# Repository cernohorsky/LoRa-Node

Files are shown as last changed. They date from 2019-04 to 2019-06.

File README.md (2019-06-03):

# LoRa Node

Simple, cheap, very small size Lora node with PCB antenna on 868 MHz. Compatible with FT232RL FTDI USB To TTL Serial Converter. Design includes lot of free GPIO's, push button and LED.

It's necessary to <b>burn bootloader with ISP before RFM95W module is soldered</b>.

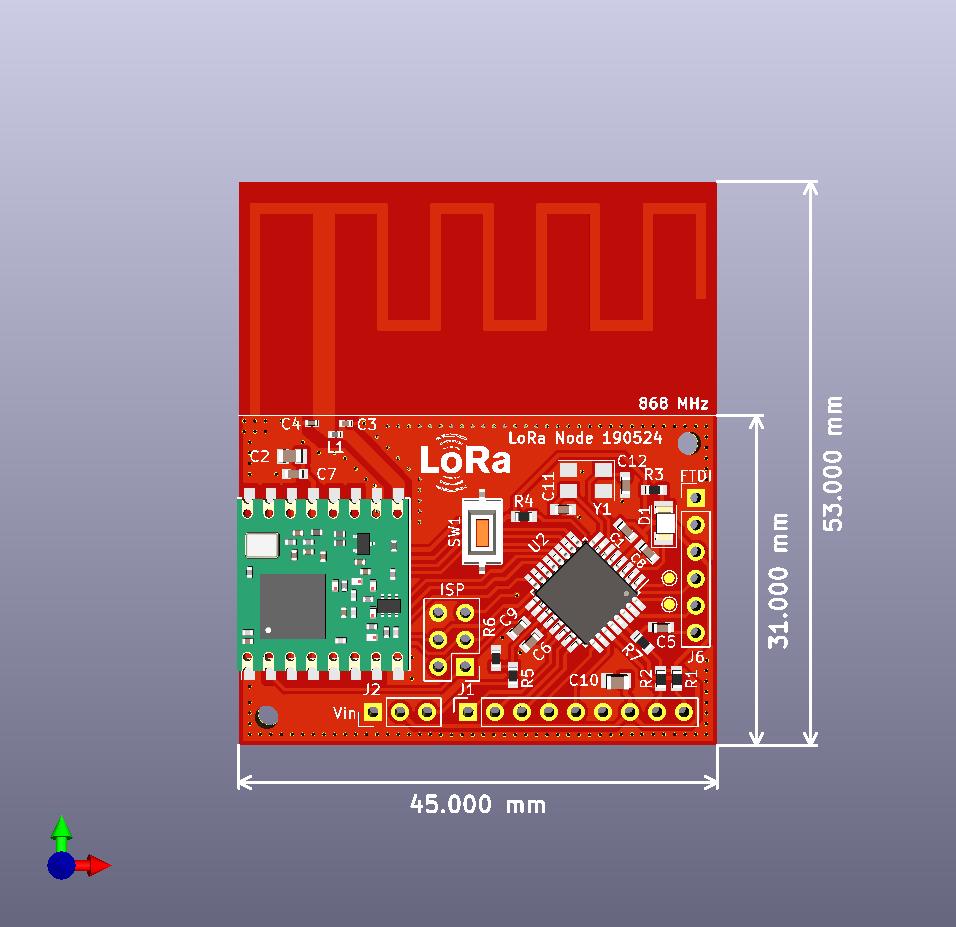
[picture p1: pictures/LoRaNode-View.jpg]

<b>Schematic</b>
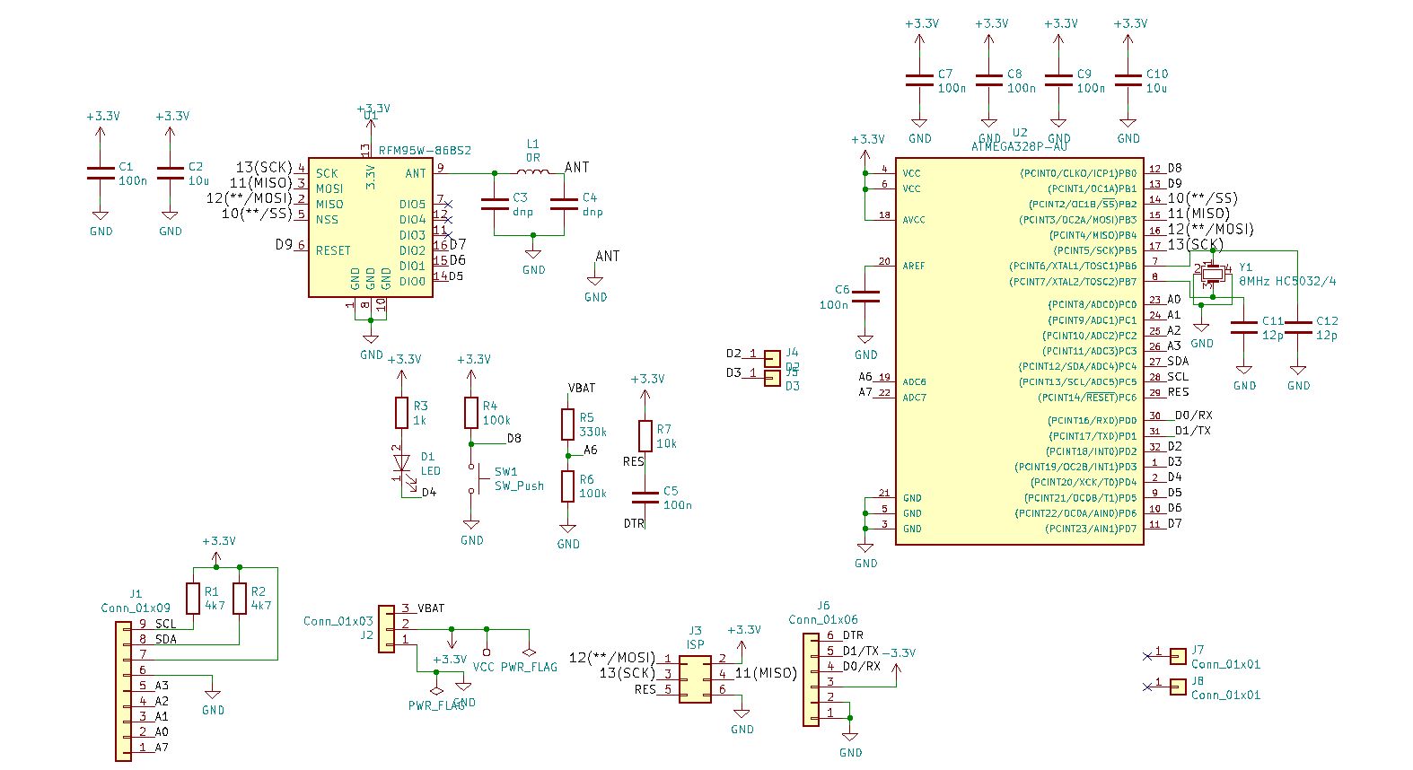
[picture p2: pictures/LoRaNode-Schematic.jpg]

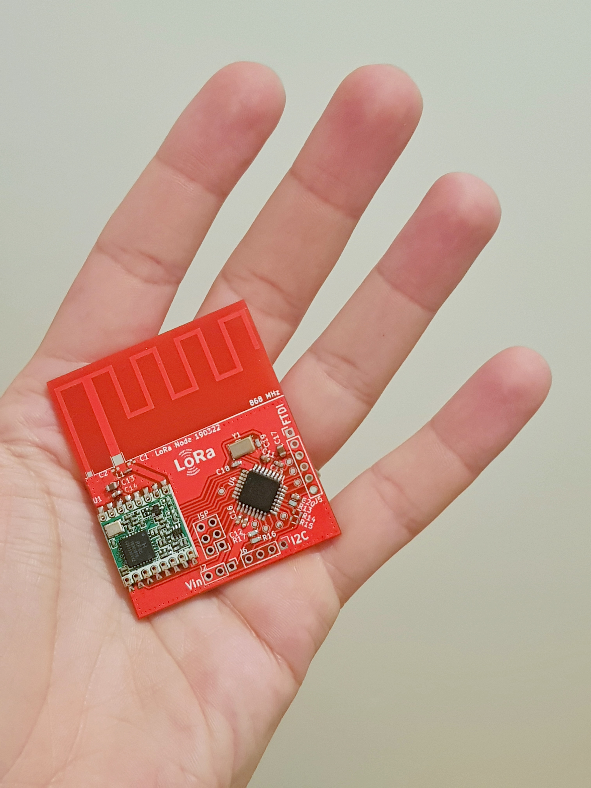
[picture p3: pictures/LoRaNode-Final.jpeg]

<b> S11 Measurement </b>
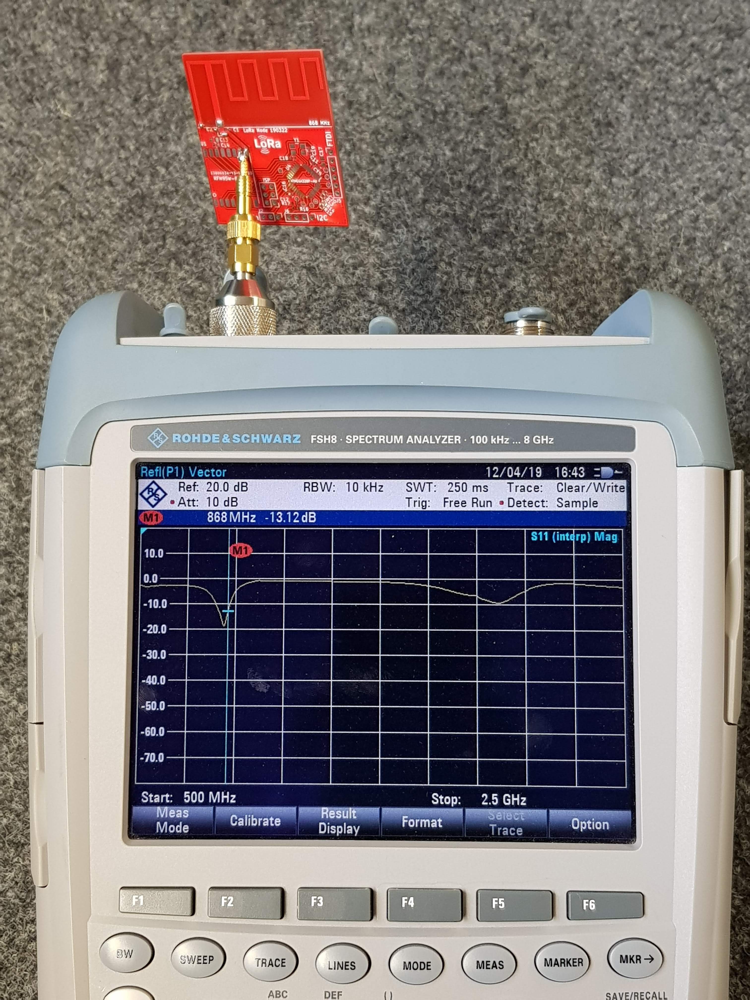
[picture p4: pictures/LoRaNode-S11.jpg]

<b> Sleep current measurement </b>
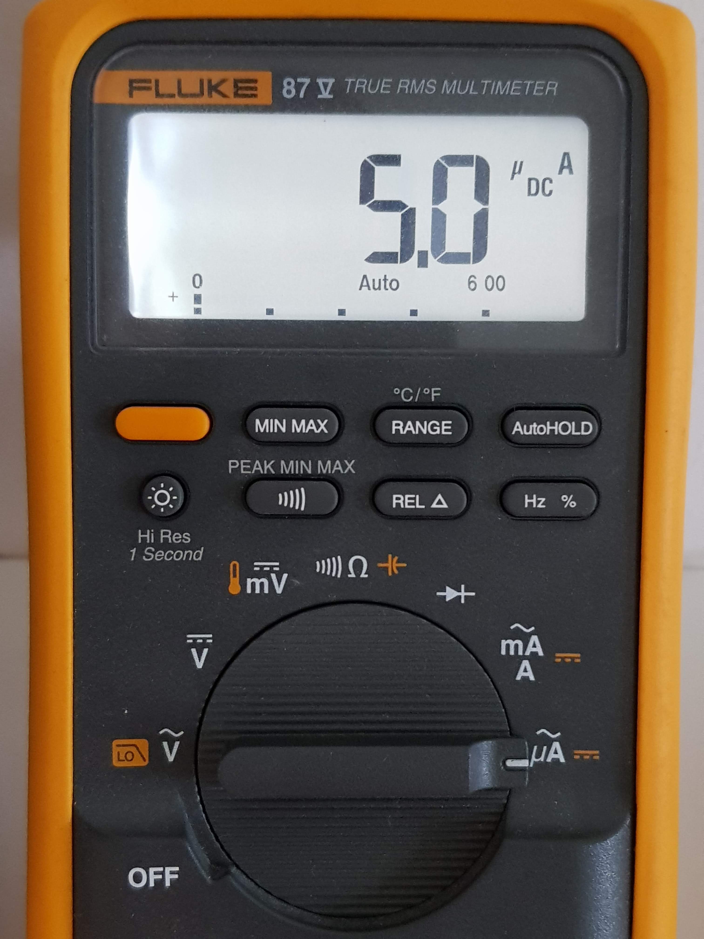
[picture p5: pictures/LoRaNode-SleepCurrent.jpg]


Based on: http://www.ti.com/lit/an/swra228c/swra228c.pdf

#RFM95W, #ATMEGA328P, #arduino, #lora, #pcb antenna, #inverted f antenna

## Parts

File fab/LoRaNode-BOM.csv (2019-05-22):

Id | Designator | Package | Quantity | Designation | Supplier and ref
17 | C1,C6,C7,C8,C9,C5 | C_0603_1608Metric | 6 | 100n
7 | C10,C2 | C_0805_2012Metric | 2 | 10u
18 | C11,C12 | C_0603_1608Metric | 2 | 12p
16 | C3,C4 | C_0402_1005Metric | 2 | dnp
15 | D1 | LED_1206_3216Metric | 1 | LED
13 | J1 | PinSocket_1x09_P2.54mm_Vertical | 1 | Conn_01x09
9 | J2 | PinHeader_1x03_P2.54mm_Vertical | 1 | Conn_01x03
2 | J3 | Pin_Header_Straight_2x03_Pitch2.54mm | 1 | ISP
3 | J6 | Pin_Header_Straight_1x06_Pitch2.54mm | 1 | Conn_01x06
19 | L1 | L_0402_1005Metric | 1 | 0R
21 | R1,R2 | R_0603_1608Metric | 2 | 4k7
14 | R3 | R_0603_1608Metric | 1 | 1k
5 | R5 | R_0603_1608Metric | 1 | 330k
6 | R6,R4 | R_0603_1608Metric | 2 | 100k
20 | R7 | R_0603_1608Metric | 1 | 10k
11 | SW1 | SMD-PushButton-6x3.6mm | 1 | SW_Push
1 | U1 | HOPERF_RFM95W_SMD | 1 | RFM95W-868S2
22 | U2 | TQFP-32_7x7mm_P0.8mm | 1 | ATMEGA328P-AU
4 | Y1 | Crystal_SMD_5032-4pin_5.0x3.2mm | 1 | 8MHz HC5032/4

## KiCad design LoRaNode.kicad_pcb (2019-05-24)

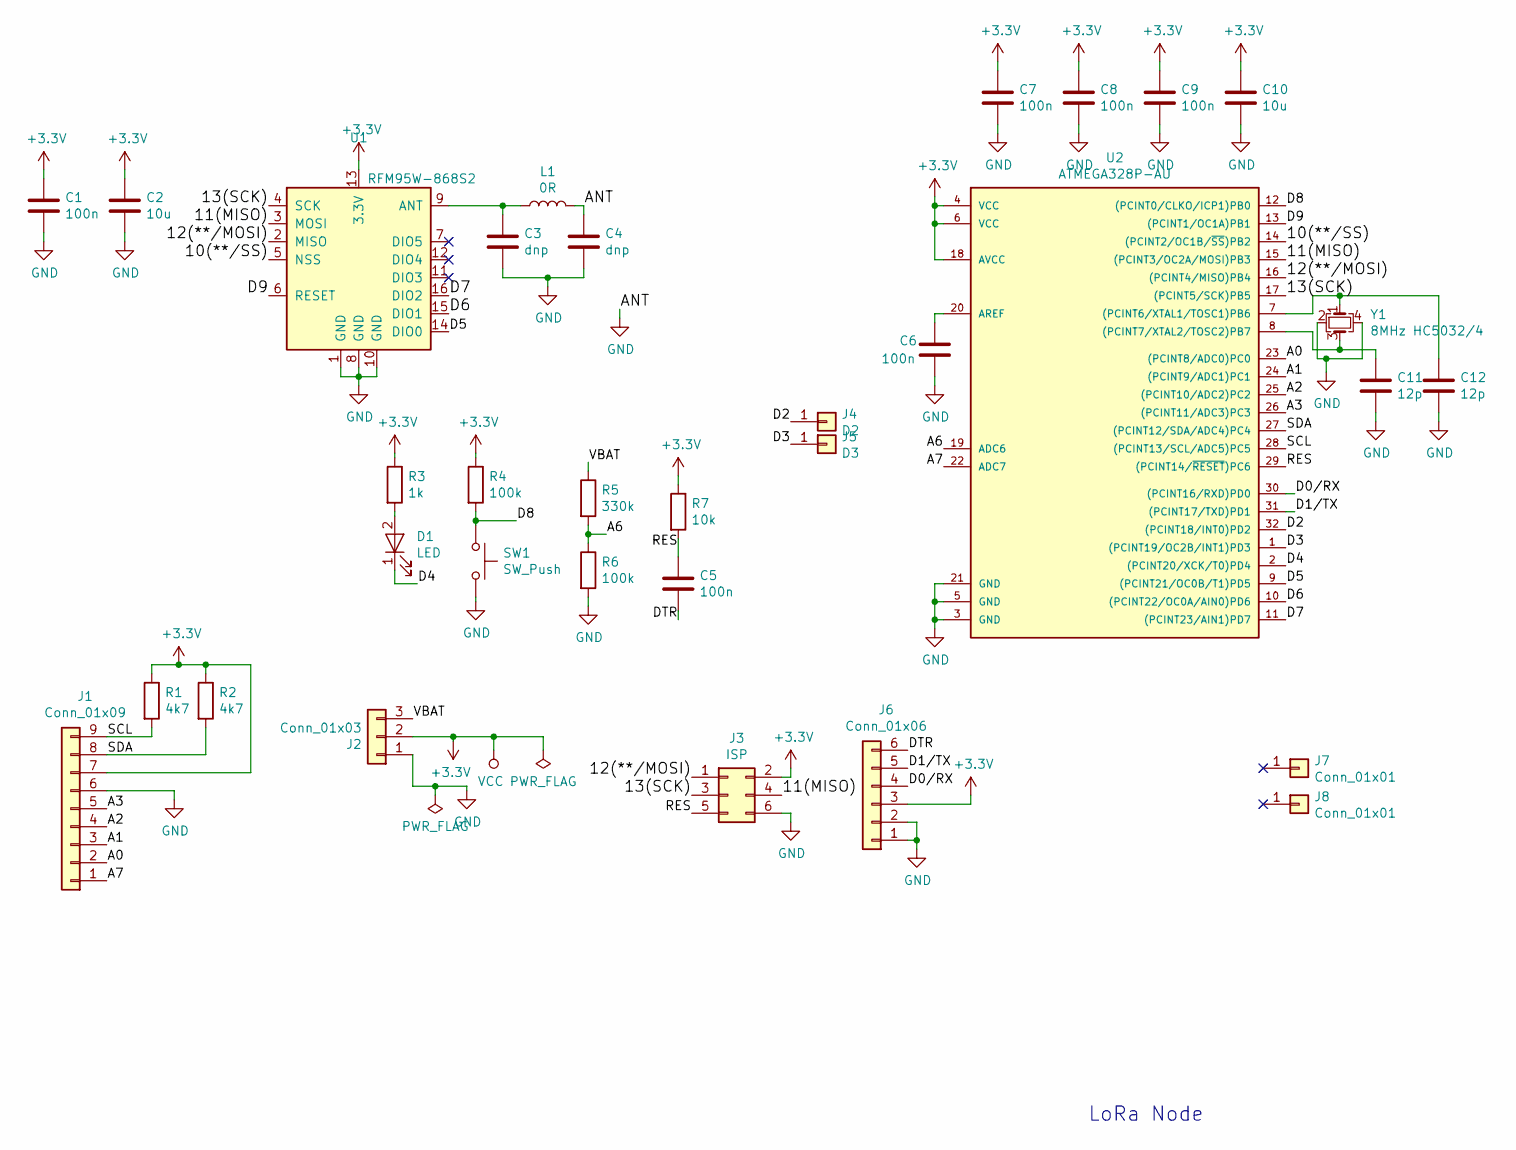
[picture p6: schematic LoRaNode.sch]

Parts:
C1, C5, C6, C7, C8, C9: 100n; C_0603_1608Metric
C2, C10: 10u; C_0805_2012Metric
C3, C4: dnp; C_0402_1005Metric
C11, C12: 12p; C_0603_1608Metric
D1: LED; LED_1206_3216Metric
J1: Conn_01x09; PinSocket_1x09_P2.54mm_Vertical
J2: Conn_01x03; PinHeader_1x03_P2.54mm_Vertical
J3: ISP; Pin_Header_Straight_2x03_Pitch2.54mm
J4: D2; TestPoint_Pad_D1.0mm
J5: D3; TestPoint_Pad_D1.0mm
J6: Conn_01x06; Pin_Header_Straight_1x06_Pitch2.54mm
J7, J8: Conn_01x01; MountingHole_2.2mm_M2
L1: 0R; L_0402_1005Metric
R1, R2: 4k7; R_0603_1608Metric
R3: 1k; R_0603_1608Metric
R4, R6: 100k; R_0603_1608Metric
R5: 330k; R_0603_1608Metric
R7: 10k; R_0603_1608Metric
SW1: SW_Push; SMD-PushButton-6x3.6mm
U1: RFM95W-868S2; HOPERF_RFM95W_SMD
U2: ATMEGA328P-AU; TQFP-32_7x7mm_P0.8mm
Y1: 8MHz HC5032/4; Crystal_SMD_5032-4pin_5.0x3.2mm

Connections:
+3V3: C1.1, C2.1, C7.1, C8.1, C9.1, C10.1, J1.7, J2.2, J3.2, J6.3, R1.1, R2.1, R3.1, R4.1, R7.1, U1.13 (3.3V), U2.4 (VCC), U2.6 (VCC), U2.18 (AVCC)
/10(**/SS): U1.5 (NSS), U2.14 ((PCINT2/OC1B/~SS~)PB2)
/11(MISO): J3.4, U1.3 (MOSI), U2.15 ((PCINT3/OC2A/MOSI)PB3)
/12(**/MOSI): J3.1, U1.2 (MISO), U2.16 ((PCINT4/MISO)PB4)
/13(SCK): J3.3, U1.4 (SCK), U2.17 ((PCINT5/SCK)PB5)
/A0: J1.2, U2.23 ((PCINT8/ADC0)PC0)
/A1: J1.3, U2.24 ((PCINT9/ADC1)PC1)
/A2: J1.4, U2.25 ((PCINT10/ADC2)PC2)
/A3: J1.5, U2.26 ((PCINT11/ADC3)PC3)
/A6: R5.2, R6.1, U2.19 (ADC6)
/A7: J1.1, U2.22 (ADC7)
/D0/RX: J6.4, U2.30 ((PCINT16/RXD)PD0)
/D1/TX: J6.5, U2.31 ((PCINT17/TXD)PD1)
/D2: J4.1, U2.32 ((PCINT18/INT0)PD2)
/D3: J5.1, U2.1 ((PCINT19/OC2B/INT1)PD3)
/D4: D1.1 (K), U2.2 ((PCINT20/XCK/T0)PD4)
/D5: U1.14 (DIO0), U2.9 ((PCINT21/OC0B/T1)PD5)
/D6: U1.15 (DIO1), U2.10 ((PCINT22/OC0A/AIN0)PD6)
/D7: U1.16 (DIO2), U2.11 ((PCINT23/AIN1)PD7)
/D8: R4.2, SW1.1, U2.12 ((PCINT0/CLKO/ICP1)PB0)
/D9: U1.6 (RESET), U2.13 ((PCINT1/OC1A)PB1)
/DTR: C5.2, J6.6
/RES: C5.1, J3.5, R7.2, U2.29 ((PCINT14/~RESET~)PC6)
/SCL: J1.9, R1.2, U2.28 ((PCINT13/SCL/ADC5)PC5)
/SDA: J1.8, R2.2, U2.27 ((PCINT12/SDA/ADC4)PC4)
/VBAT: J2.3, R5.1
GND: C1.2, C2.2, C3.2, C4.1, C4.2, C6.2, C7.2, C8.2, C9.2, C10.2, C11.2, C12.2, J1.6, J2.1, J3.6, J6.1, J6.2, L1.2, R6.2, SW1.2, U1.1 (GND), U1.8 (GND), U1.10 (GND), U2.3 (GND), U2.5 (GND), U2.21 (GND), Y1.2, Y1.4
unnamed: C3.1, L1.1, U1.9 (ANT)
unnamed: C6.1, U2.20 (AREF)
unnamed: C11.1, U2.8 ((PCINT7/XTAL2/TOSC2)PB7), Y1.3
unnamed: C12.1, U2.7 ((PCINT6/XTAL1/TOSC1)PB6), Y1.1
unnamed: D1.2 (A), R3.2

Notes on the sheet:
LoRa Node

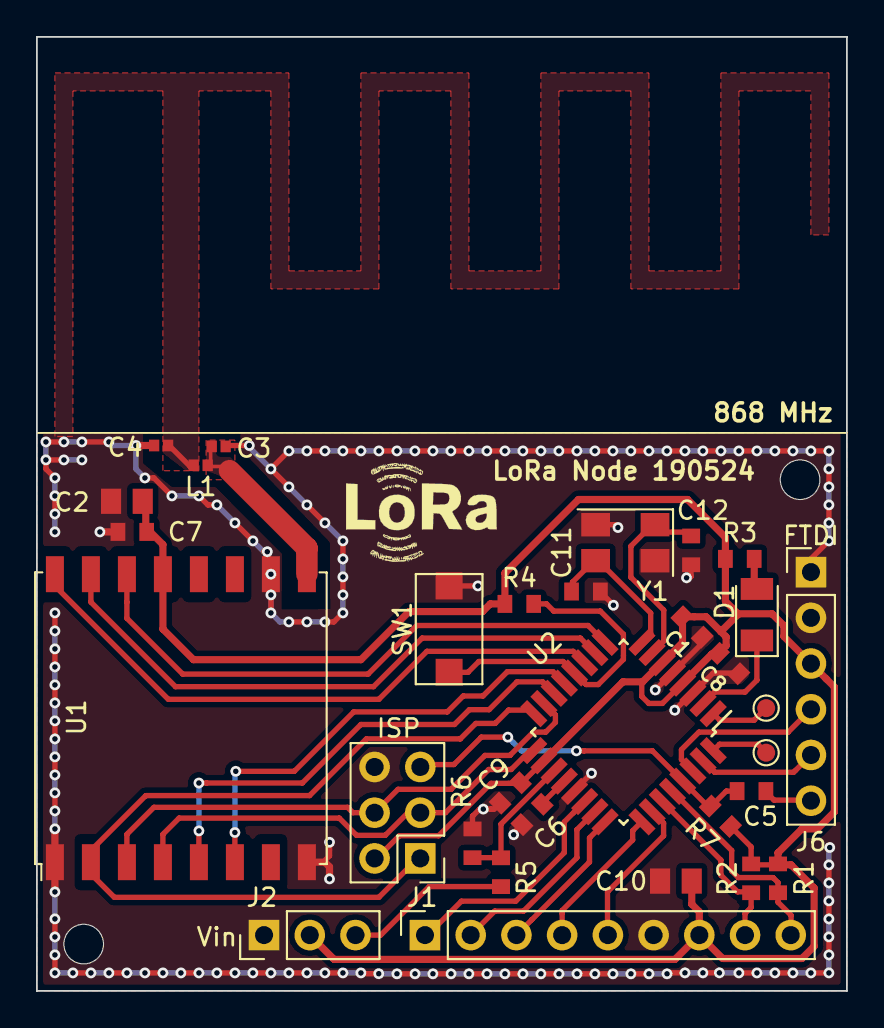
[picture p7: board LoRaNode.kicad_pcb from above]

Board: 2 copper layers, 45.0 x 53.0 mm, 33 parts (0 on the bottom side), 32 nets.

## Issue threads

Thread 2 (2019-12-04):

What board thickness is used?

Neumi, 2019-12-04:
If im not wrong board thickness has an influence on the impedance in the RF circuit and feed line. Can you tell what board you're using?
Thanks alot for the share!

krlc, 2020-05-30:
@Neumi from TI source provided:
> The antenna was implemented on a 0.8 mm thick FR-4 substrate. Since there is no  ground  plane  beneath  the  antenna  the  PCB  thickness  is  not  critical

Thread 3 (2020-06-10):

pcb antenna design

maxholgasson, 2020-06-10:
Hi,

which inductor L1 is used in the circuit? Also which values or specific caps for C3 and C4?
Thanks

miqmago, 2024-02-20:
@maxholgasson on BOM I've seen that L1 is 0R and C3 and C4 are not placed. From the TI design referenced on readme, it seems to me that they are not needed if the ground plane is 31x45mm.

I'm not sure about L1, as you closed the issue as resolved, could you confirm if it can be skipped and wired it directly to RFM95W ANT pin?

Closed 2020-06-16.

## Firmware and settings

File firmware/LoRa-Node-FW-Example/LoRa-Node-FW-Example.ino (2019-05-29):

// MIT License
// https://github.com/gonzalocasas/arduino-uno-dragino-lorawan/blob/master/LICENSE
// Based on examples from https://github.com/matthijskooijman/arduino-lmic
// Copyright (c) 2015 Thomas Telkamp and Matthijs Kooijman
// Adaptions: Andreas Spiess

#include <lmic.h>
#include <hal/hal.h>
//#include <credentials.h>

static const u1_t NWKSKEY[16] = { 0x06, 0xD0, 0xA5, 0xA5, 0x8D, 0xE5, 0x6E, 0x61, 0xE1, 0x43, 0xCD, 0x58, 0x54, 0x9E, 0xF9, 0x4F };
static const u1_t APPSKEY[16] = { 0xDA, 0xEA, 0xA6, 0x3E, 0x28, 0x7D, 0xAF, 0xF4, 0xCA, 0x5F, 0xE2, 0x42, 0xB3, 0xA8, 0xF9, 0x46 };
static const u4_t DEVADDR = 0x25011788;

#include <CayenneLPP.h>
#include <LowPower.h>

CayenneLPP lpp(uint8_t size);

//Sleep time/min
int sleepTime=1;

// These callbacks are only used in over-the-air activation, so they are
// left empty here (we cannot leave them out completely unless
// DISABLE_JOIN is set in config.h, otherwise the linker will complain).
void os_getArtEui (u1_t* buf) { }
void os_getDevEui (u1_t* buf) { }
void os_getDevKey (u1_t* buf) { }

static osjob_t sendjob;

unsigned long readVcc() { 
  long result; // Read 1.1V reference against AVcc 
  ADMUX = _BV(REFS0) | _BV(MUX3) | _BV(MUX2) | _BV(MUX1); 
  delay(2); // Wait for Vref to settle 
  ADCSRA |= _BV(ADSC); // Convert 
  while (bit_is_set(ADCSRA,ADSC)); 
  result = ADCL; 
  result |= ADCH<<8; 
  result = 1126400L / result; // Back-calculate AVcc in mV 
  return result; 
}

// Schedule TX every this many seconds (might become longer due to duty
// cycle limitations).
const unsigned TX_INTERVAL = 0;

// Pin mapping Dragino Shield
const lmic_pinmap lmic_pins = {
    .nss = 10,
    .rxtx = LMIC_UNUSED_PIN,
    .rst = 9,
    .dio = {5, 6, 7},
};
void onEvent (ev_t ev) {
    if (ev == EV_TXCOMPLETE) {
        Serial.println(F("EV_TXCOMPLETE (includes waiting for RX windows)"));
        // Schedule next transmission
        //os_setTimedCallback(&sendjob, os_getTime()+sec2osticks(TX_INTERVAL), do_send);

        //Sleep for requested time
        hal_sleep();  //Module sleep
        for (int i=0; i<sleepTime*6; i++) {
         //Use library from https://github.com/rocketscream/Low-Power
        LowPower.powerDown(SLEEP_8S, ADC_OFF, BOD_OFF);
        }
        
        //Send next payload
        do_send(&sendjob);        
    }
}

void do_send(osjob_t* j){
  
//---------------------------------------------
//Put your code here
//---------------------------------------------

  //https://www.thethingsnetwork.org/docs/devices/arduino/api/cayennelpp.html 
  CayenneLPP lpp(51);

  lpp.reset();
    
  while (readVcc()<3000) {
    LowPower.powerDown(SLEEP_8S, ADC_OFF, BOD_OFF);
  }
  
  float u = readVcc();
  lpp.addAnalogInput(1, u/1000);
  
  Serial.print("Napeti baterie: ");
  Serial.print(u);
  Serial.println(" V");

  //lpp.addTemperature(1, 22.3);
  //lpp.addBarometricPressure(2, 1073.21);
  //lpp.addGPS(3, 52.37365, 4.88650, 2);

  // Payload to send (uplink)
  //static uint8_t message[] = "0";

//---------------------------------------------
// End of user code
//---------------------------------------------

    // Check if there is not a current TX/RX job running
    if (LMIC.opmode & OP_TXRXPEND) {
        Serial.println(F("OP_TXRXPEND, not sending"));
    } else {
        // Prepare upstream data transmission at the next possible time.
        //LMIC_setTxData2(1, lpp.getBuffer(),  lpp.getSize()-1, 0);
        LMIC_setTxData2(1, lpp.getBuffer(),  lpp.getSize(), 0);
        Serial.println(F("Sending uplink packet..."));
    }
    // Next TX is scheduled after TX_COMPLETE event.
    
}

void setup() {
    Serial.begin(115200);
    Serial.println(F("Starting..."));
      
    // LMIC init
    os_init();
    
    // Reset the MAC state. Session and pending data transfers will be discarded.
    LMIC_reset();    
    
    // Set static session parameters.
    LMIC_setSession (0x1, DEVADDR, NWKSKEY, APPSKEY);

    // Disable link check validation
    LMIC_setLinkCheckMode(0);

    // TTN uses SF9 for its RX2 window.
    LMIC.dn2Dr = DR_SF9;
    
    for (int i = 1; i <= 8; i++) {
      LMIC_disableChannel(i);
      }
      
    // Set data rate and transmit power for uplink (note: txpow seems to be ignored by the library)
    LMIC_setDrTxpow(DR_SF7,14);

    // Start job
    do_send(&sendjob);
    //delay(5000);
    
}

void loop() {
    os_runloop_once();
    //delay(5000);
}

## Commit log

2019-03-22 Moved I2C and Power connectors, Added antenna test pads, ERC done, DRC done
    [LoRaNode.kicad_pcb, LoRaNode.sch]
2019-03-22 Changed I2C pinout
    [LoRaNode.kicad_pcb, LoRaNode.sch]
2019-03-22 Small changes
    [DN023-868MHz-F-Antenna.kicad_pcb]
2019-03-22 PCB manufactured
    [LoRaNode-B.Cu.gbr, LoRaNode-B.Mask.gbr, LoRaNode-B.SilkS.gbr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]
2019-05-13 Silkscreen correction, removed antenna testing pads
    [LoRaNode.kicad_pcb, LoRaNode.sch]
2019-05-17 Added more 5 GPIO's and push button
    [LoRaNode.kicad_pcb, LoRaNode.sch]
2019-05-20 Added LED, changed footprints to actual KiCAD library
    [LoRaNode.kicad_pcb, _saved_LoRaNode.sch]
2019-05-20 Changed RFM95W footprint
    [LoRaNode.kicad_pcb]
2019-05-21 Added mounting holes
    [LoRaNode-BOM.ods, LoRaNode.kicad_pcb, LoRaNode.sch]
2019-05-21 Updated RFM95W 3D model
    [LoRaNode.kicad_pcb]
2019-05-21 Updated schematic
2019-05-22 Anotation reset, added BOM
    [DN023-868MHz-F-Antenna.kicad_pcb, LoRaNode-BOM.csv, LoRaNode-BOM.ods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]
2019-05-24 Corrected silk layer, removed old footprint files
    [LoRaNode.kicad_pcb]
2019-06-02 Added sleep current measurement result
